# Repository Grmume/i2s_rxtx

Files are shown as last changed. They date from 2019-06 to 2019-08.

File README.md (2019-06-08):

# i2s_rxtx
Receiver and and (active) transmitter for I2S over ethernet cables.

Receiver for the 4 channels of digital audio (i2s) which can be transmitted using ethernet cables (>=Cat5).
Has a pin header to choose which channel is send to the i2s output, which can then be directed to an amp.
Contains an active transmitter to transmit all channels further to the next receiver.

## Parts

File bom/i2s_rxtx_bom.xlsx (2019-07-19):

Board | i2s_rxtx
BOM
References | Value | Footprint | Datasheet | Supplier1 Partnumber | Supplier2 Partnumber | Count | URL Reichelt | Unit Pr. Reichelt
C1 | 10µF | Capacitor_SMD:CP_Elec_6.3x5.4 | ~ |  |  | 1 | https://www.reichelt.de/smd-elko-10-f-50-v-85-c-2000-h-20-s-v-10u-50-p228473.html?&trstct=pol_5 | 0.18 €
> C2, C4, C6, C8 | 100nF | Capacitor_SMD:C_0805_2012Metric_Pad1.15x1.40mm_HandSolder |  |  |  | 4
C3 | 2.2µF | Capacitor_SMD:C_0805_2012Metric_Pad1.15x1.40mm_HandSolder |  |  |  | 1
> C5, C7, C9 | 10nF | Capacitor_SMD:C_0805_2012Metric_Pad1.15x1.40mm_HandSolder |  |  |  | 3
> H1-H4 | MountingHole | MountingHole:MountingHole_3.2mm_M3_Pad | ~ |  |  | 4
IC1 | AM26C32 | agg:SOIC-16 | http://www.ti.com/lit/ds/symlink/am26c32.pdf | 1121592 | 595-AM26C32QDR | 1
> IC2, IC3 | AM26C31 | agg:SOIC-16 | http://www.ti.com.cn/cn/lit/ds/symlink/am26c31.pdf | 4975637 |  | 2
J1 | CONN_01x02 | Connector_PinHeader_2.00mm:PinHeader_1x02_P2.00mm_Vertical |  |  |  | 1
> J2, J4, J5 | RJ45_Shielded | agg:RJ45_Weidmueller | ~ |  |  | 3
J3 | CONN_01x05 | Connector_PinHeader_2.00mm:PinHeader_1x05_P2.00mm_Vertical |  |  |  | 1
> R1-R4 | 100R | Resistor_SMD:R_1206_3216Metric_Pad1.42x1.75mm_HandSolder |  |  |  | 4
> R5-R8 | 500K | Resistor_SMD:R_0805_2012Metric_Pad1.15x1.40mm_HandSolder |  |  |  | 4

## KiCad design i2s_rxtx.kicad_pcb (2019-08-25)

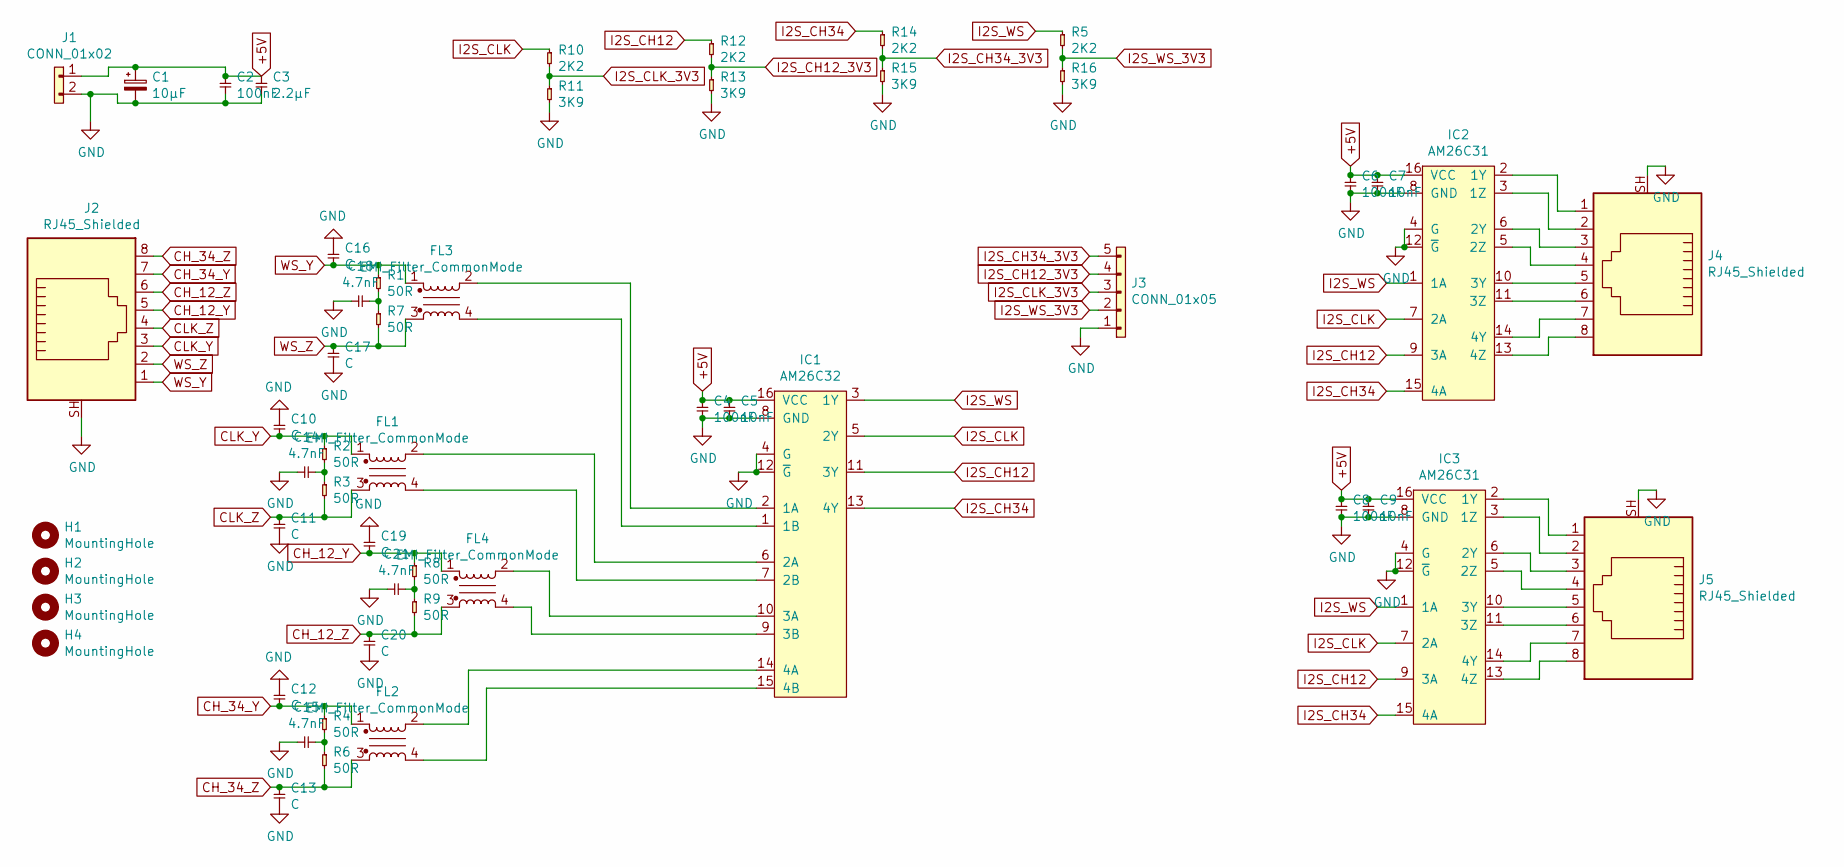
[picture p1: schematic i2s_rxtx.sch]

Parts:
C1: 10µF; CP_Elec_6.3x5.4
C2, C4, C6, C8: 100nF; C_0805_2012Metric_Pad1.15x1.40mm_HandSolder
C3: 2.2µF; C_0805_2012Metric_Pad1.15x1.40mm_HandSolder
C5, C7, C9: 10nF; C_0805_2012Metric_Pad1.15x1.40mm_HandSolder
C10, C11, C12, C13, C16, C17, C19, C20: C; C_0805_2012Metric_Pad1.15x1.40mm_HandSolder
C14, C15, C18, C21: 4.7nF; C_0805_2012Metric_Pad1.15x1.40mm_HandSolder
FL1, FL2, FL3, FL4: EMI_Filter_CommonMode; B82789_PinSwap
H1, H2, H3, H4: MountingHole; MountingHole_3.2mm_M3_Pad
IC1: AM26C32; SOIC-16; Farnell 1121592
IC2, IC3: AM26C31; SOIC-16; Farnell 4975637
J1: CONN_01x02; PinHeader_1x02_P2.00mm_Vertical
J2, J4, J5: RJ45_Shielded; RJ45_Weidmueller
J3: CONN_01x05; PinHeader_1x05_P2.00mm_Vertical
R1, R2, R3, R4, R6, R7, R8, R9: 50R; R_0805_2012Metric_Pad1.15x1.40mm_HandSolder
R5, R10, R12, R14: 2K2; R_0805_2012Metric_Pad1.15x1.40mm_HandSolder
R11, R13, R15, R16: 3K9; R_0805_2012Metric_Pad1.15x1.40mm_HandSolder

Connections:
+5V: C1.1, C2.1, C3.1, C4.1, C5.1, C6.1, C7.1, C8.1, C9.1, IC1.16 (VCC), IC2.16 (VCC), IC3.16 (VCC), J1.1
CH_12_Y: C19.2, FL4.1, J2.5, R8.1
CH_12_Z: C20.1, FL4.3, J2.6, R9.2
CH_34_Y: C12.2, FL2.1, J2.7, R4.1
CH_34_Z: C13.1, FL2.3, J2.8, R6.2
CLK_Y: C10.2, FL1.1, J2.3, R2.1
CLK_Z: C11.1, FL1.3, J2.4, R3.2
GND: C1.2, C2.2, C3.2, C4.2, C5.2, C6.2, C7.2, C8.2, C9.2, C10.1, C11.2, C12.1, C13.2, C14.1, C15.1, C16.1, C17.2, C18.1, C19.1, C20.2, C21.1, IC1.4 (G), IC1.8 (GND), IC1.12 (~G), IC2.4 (G), IC2.8 (GND), IC2.12 (~G), IC3.4 (G), IC3.8 (GND), IC3.12 (~G), J1.2, J2.SH, J3.1, J4.SH, J5.SH, R11.2, R13.2, R15.2, R16.2
I2S_CH12: IC1.11 (3Y), IC2.9 (3A), IC3.9 (3A), R12.1
I2S_CH12_3V3: J3.4, R12.2, R13.1
I2S_CH34: IC1.13 (4Y), IC2.15 (4A), IC3.15 (4A), R14.1
I2S_CH34_3V3: J3.5, R14.2, R15.1
I2S_CLK: IC1.5 (2Y), IC2.7 (2A), IC3.7 (2A), R10.1
I2S_CLK_3V3: J3.3, R10.2, R11.1
I2S_WS: IC1.3 (1Y), IC2.1 (1A), IC3.1 (1A), R5.1
I2S_WS_3V3: J3.2, R5.2, R16.1
unnamed: C14.2, R2.2, R3.1
unnamed: C15.2, R4.2, R6.1
unnamed: C18.2, R1.2, R7.1
unnamed: C21.2, R8.2, R9.1
unnamed: FL1.2, IC1.6 (2A)
unnamed: FL1.4, IC1.7 (2B)
unnamed: FL2.2, IC1.14 (4A)
unnamed: FL2.4, IC1.15 (4B)
unnamed: FL3.2, IC1.2 (1A)
unnamed: FL3.4, IC1.1 (1B)
unnamed: FL4.2, IC1.10 (3A)
unnamed: FL4.4, IC1.9 (3B)
unnamed: IC2.2 (1Y), J4.1
unnamed: IC2.3 (1Z), J4.2
unnamed: IC2.5 (2Z), J4.4
unnamed: IC2.6 (2Y), J4.3
unnamed: IC2.10 (3Y), J4.5
unnamed: IC2.11 (3Z), J4.6
unnamed: IC2.13 (4Z), J4.8
unnamed: IC2.14 (4Y), J4.7
unnamed: IC3.2 (1Y), J5.1
unnamed: IC3.3 (1Z), J5.2
unnamed: IC3.5 (2Z), J5.4
unnamed: IC3.6 (2Y), J5.3
unnamed: IC3.10 (3Y), J5.5
unnamed: IC3.11 (3Z), J5.6
unnamed: IC3.13 (4Z), J5.8
unnamed: IC3.14 (4Y), J5.7
WS_Y: C16.2, FL3.1, J2.1, R1.1
WS_Z: C17.1, FL3.3, J2.2, R7.2

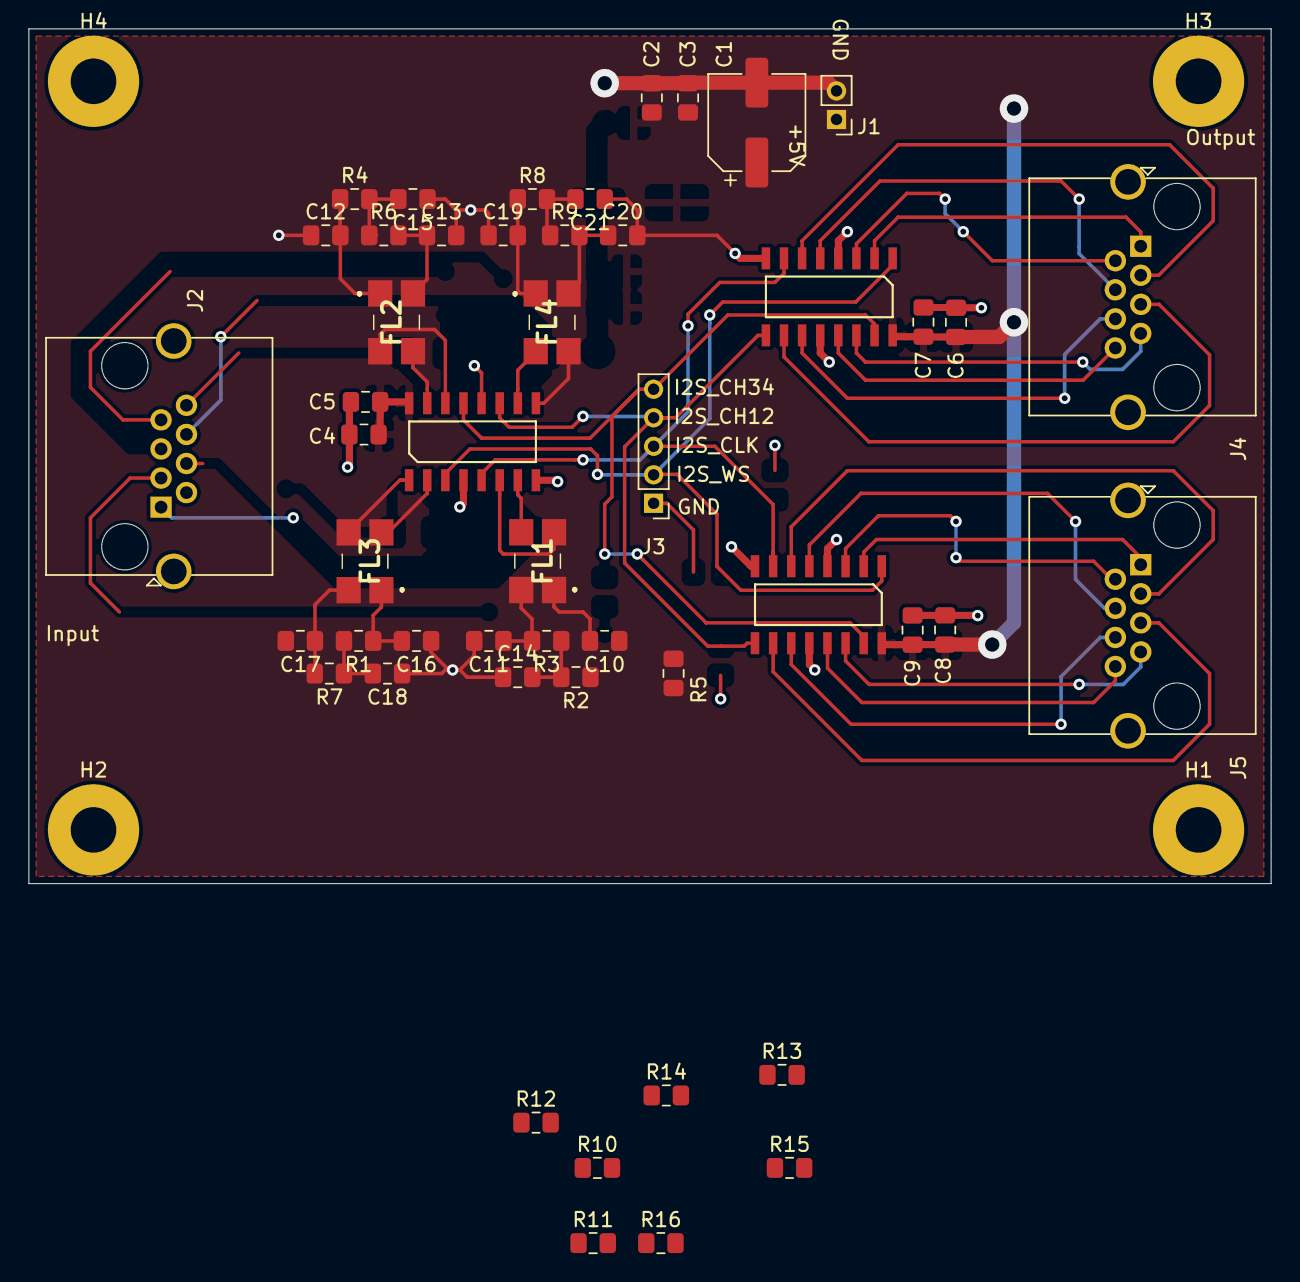
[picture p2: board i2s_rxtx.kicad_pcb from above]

Board: 2 copper layers, 87.1 x 59.9 mm, 53 parts (0 on the bottom side), 46 nets.

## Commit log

2019-06-08 -- added receiver and transmitter
    [i2s_rxtx.kicad_pcb, i2s_rxtx.sch]
2019-06-15 -- update
    [i2s_rxtx-B_Cu.gbr, i2s_rxtx-B_Mask.gbr, i2s_rxtx-B_SilkS.gbr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]
2019-06-16 -- updated gerbers
    [i2s_rxtx-B_Cu.gbr, i2s_rxtx-B_Mask.gbr, i2s_rxtx-B_SilkS.gbr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]
2019-06-16 -- changed vias
    [i2s_rxtx-B_Cu.gbr, i2s_rxtx-B_Mask.gbr, i2s_rxtx-B_SilkS.gbr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]
2019-06-16 -- added mounting holes
    [i2s_rxtx-B_Cu.gbr, i2s_rxtx-B_Mask.gbr, i2s_rxtx-B_SilkS.gbr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]
2019-06-16 -- update gerbers zip
2019-07-19 -- added bom
    [i2s_rxtx_bom.xlsx]
2019-08-14 -- added voltage divider for 3.3V outputs
    [i2s_rxtx.sch]
2019-08-16 -- updated termination network replaced termination resistor by a split termination added common mode chokes added capacitors
    [i2s_rxtx.sch]
2019-08-17 -- added capacitors to data lines
    -- added spreadsheet to calculate capacitor values based on sample rate
    [capacitors_sample_frequency.csv, capacitors_sample_frequency.xlsx, i2s_rxtx.sch]
2019-08-25 adjusted pcb layout to new termination network
    [i2s_rxtx.kicad_pcb, i2s_rxtx.sch]
